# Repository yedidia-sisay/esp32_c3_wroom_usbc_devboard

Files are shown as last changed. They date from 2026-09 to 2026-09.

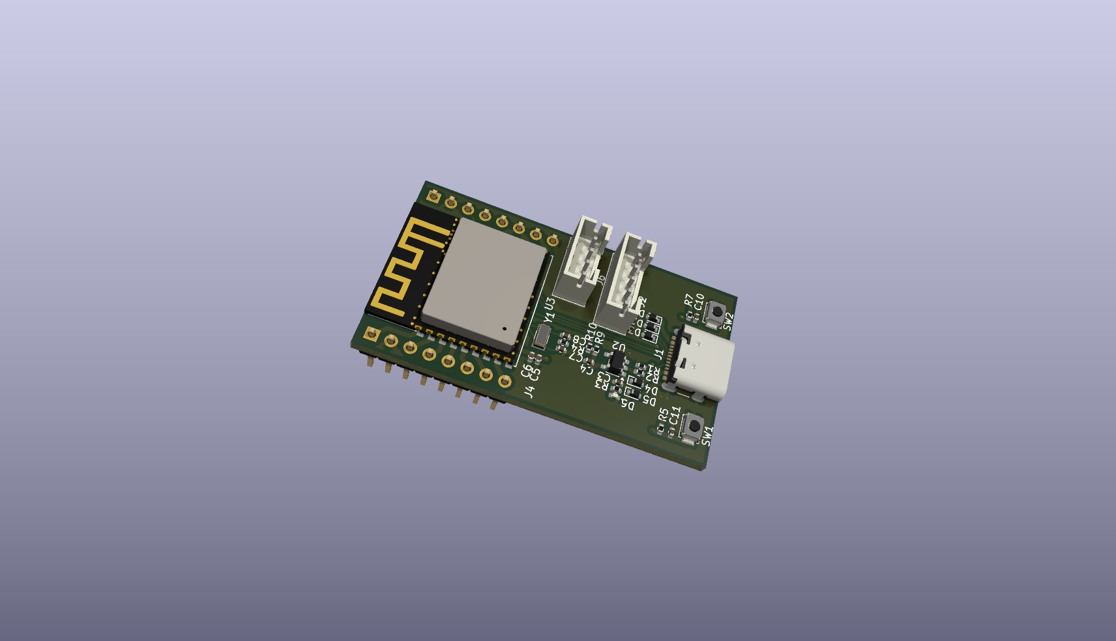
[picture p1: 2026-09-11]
esp32_devboard/esp32_devboard_1.png

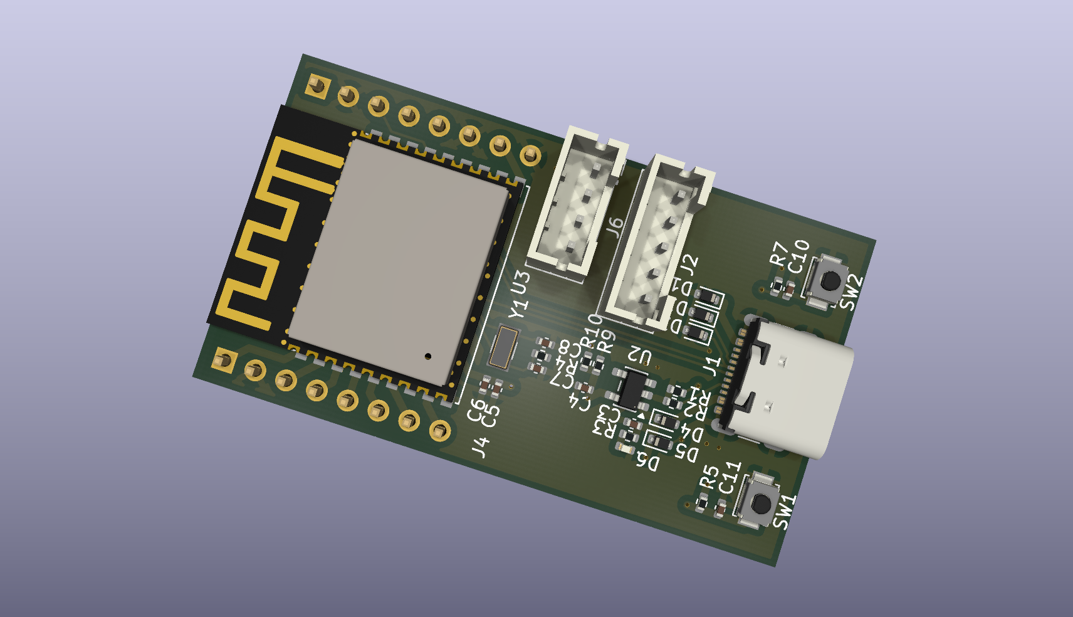
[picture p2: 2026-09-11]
esp32_devboard/esp32_devboard_2.png

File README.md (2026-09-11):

# ESP32-C3 Custom Development Board

A custom ESP32-C3 development board designed from the ground up in **KiCad**, covering schematic design, component selection, PCB layout, and routing.

The board is built around the **ESP32-C3-WROOM-02** and provides USB-C connectivity, regulated 3.3 V power, programming/debugging interfaces, GPIO expansion, and basic user controls.

## Overview

The goal of this project was to design a practical, compact ESP32-C3 development board rather than relying on an off-the-shelf development board.

The design integrates the ESP32-C3 module with the supporting power, USB, reset, boot, programming, and expansion circuitry required for a usable development platform.

## Features

* **ESP32-C3-WROOM-02** module
* **USB-C** connector
* USB 2.0 D+ / D− connectivity
* USB-C CC resistors
* USB ESD/TVS protection
* **5 V USB input**
* **3.3 V regulated supply**
* AP2112K-3.3 LDO
* Reset / CHIP_PU circuitry
* Boot-mode control
* User/status LED
* GPIO expansion headers
* Dedicated JTAG/UART access
* Exposed 3.3 V, 5 V, and GND connections
* Custom PCB layout and routing

## Hardware

### Main MCU

The board uses the **Espressif ESP32-C3-WROOM-02** module.

The module provides the main processing, USB connectivity, GPIO, UART, and debugging interfaces for the board.

The schematic exposes the ESP32-C3 GPIOs through headers so the board can be used for firmware development and hardware experimentation.

### USB-C

USB-C is used as the primary connection to the board.

The USB interface includes:

* VBUS power input
* USB D+
* USB D−
* CC1 / CC2 configuration resistors
* USB ESD/TVS protection
* Shield connection

The USB data lines connect directly to the ESP32-C3's native USB interface.

### Power

The board accepts **5 V from USB-C**.

A dedicated **AP2112K-3.3 LDO** generates the 3.3 V rail used by the ESP32-C3 and associated circuitry.
Decoupling capacitors are included around the power circuitry and ESP32-C3 supply.

### Reset and Boot

The board includes dedicated push buttons and supporting resistors for:

* ESP32 reset / CHIP_PU
* Boot-mode selection

This allows the module to be manually reset and placed into the required boot mode during firmware development.

### Programming and Debugging

The design exposes the ESP32-C3's programming/debugging signals through dedicated headers.

Interfaces available on the board include:

* UART
* JTAG
* GPIO
* 3.3 V
* 5 V
* GND

### GPIO Expansion

Two multi-pin headers provide access to the ESP32-C3 GPIOs.

This allows external sensors, peripherals, and prototype circuits to be connected without modifying the main PCB.

## PCB Design

The schematic and PCB were designed in **KiCad 10**.

The PCB design process included:

1. Component selection
2. Schematic capture
3. Electrical connectivity definition
4. Component footprint assignment
5. PCB placement
6. Power and signal routing
7. USB routing
8. Ground-plane implementation
9. Design-rule checking
10. Final PCB routing

The design was developed with the intention of producing a physically usable development board rather than being purely a schematic exercise.

# Project Status

**Hardware design completed.**

The schematic and PCB routing have been completed. The next stage is hardware fabrication and bring-up, followed by firmware testing and validation of the USB, power, GPIO, and programming interfaces.
## Author

**Yedidia Sisay**

Electrical Engineering | Embedded Systems | PCB Design

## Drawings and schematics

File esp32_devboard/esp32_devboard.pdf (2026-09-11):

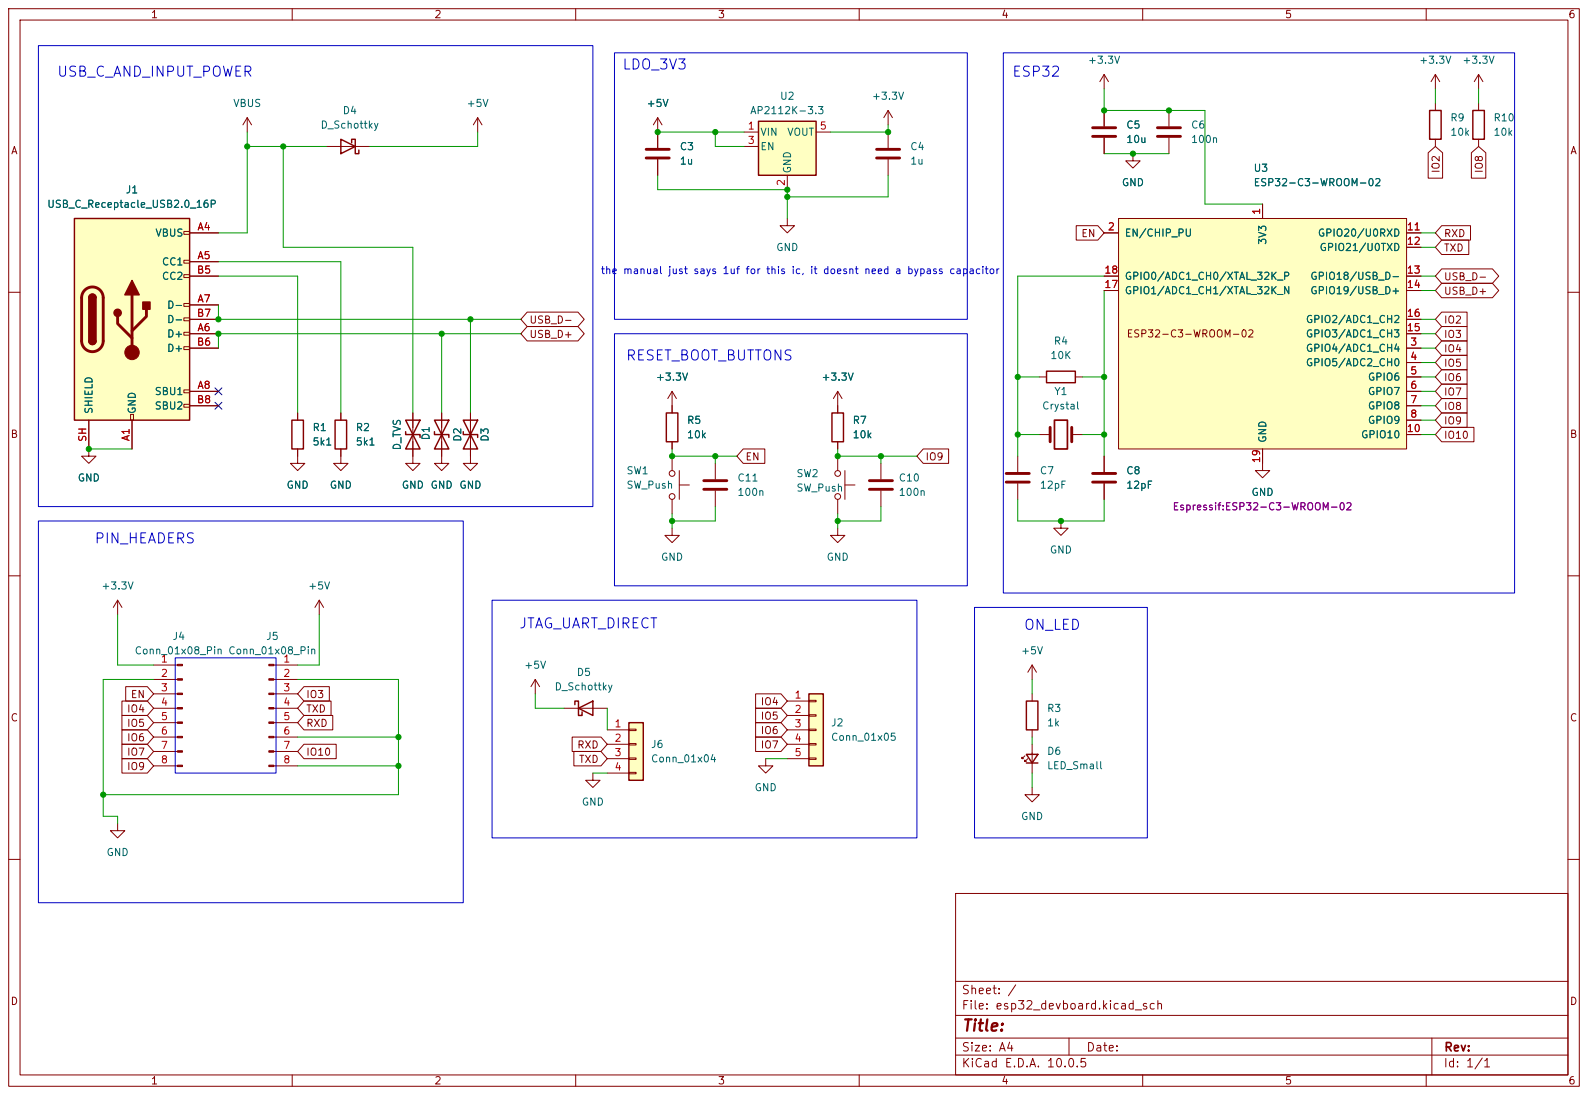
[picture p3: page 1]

the manual just says 1uf for this ic, it doesnt need a bypass capacitor

Size: A4 | Rev:
KiCad E.D.A. 10.0.5 | Id: 1/1

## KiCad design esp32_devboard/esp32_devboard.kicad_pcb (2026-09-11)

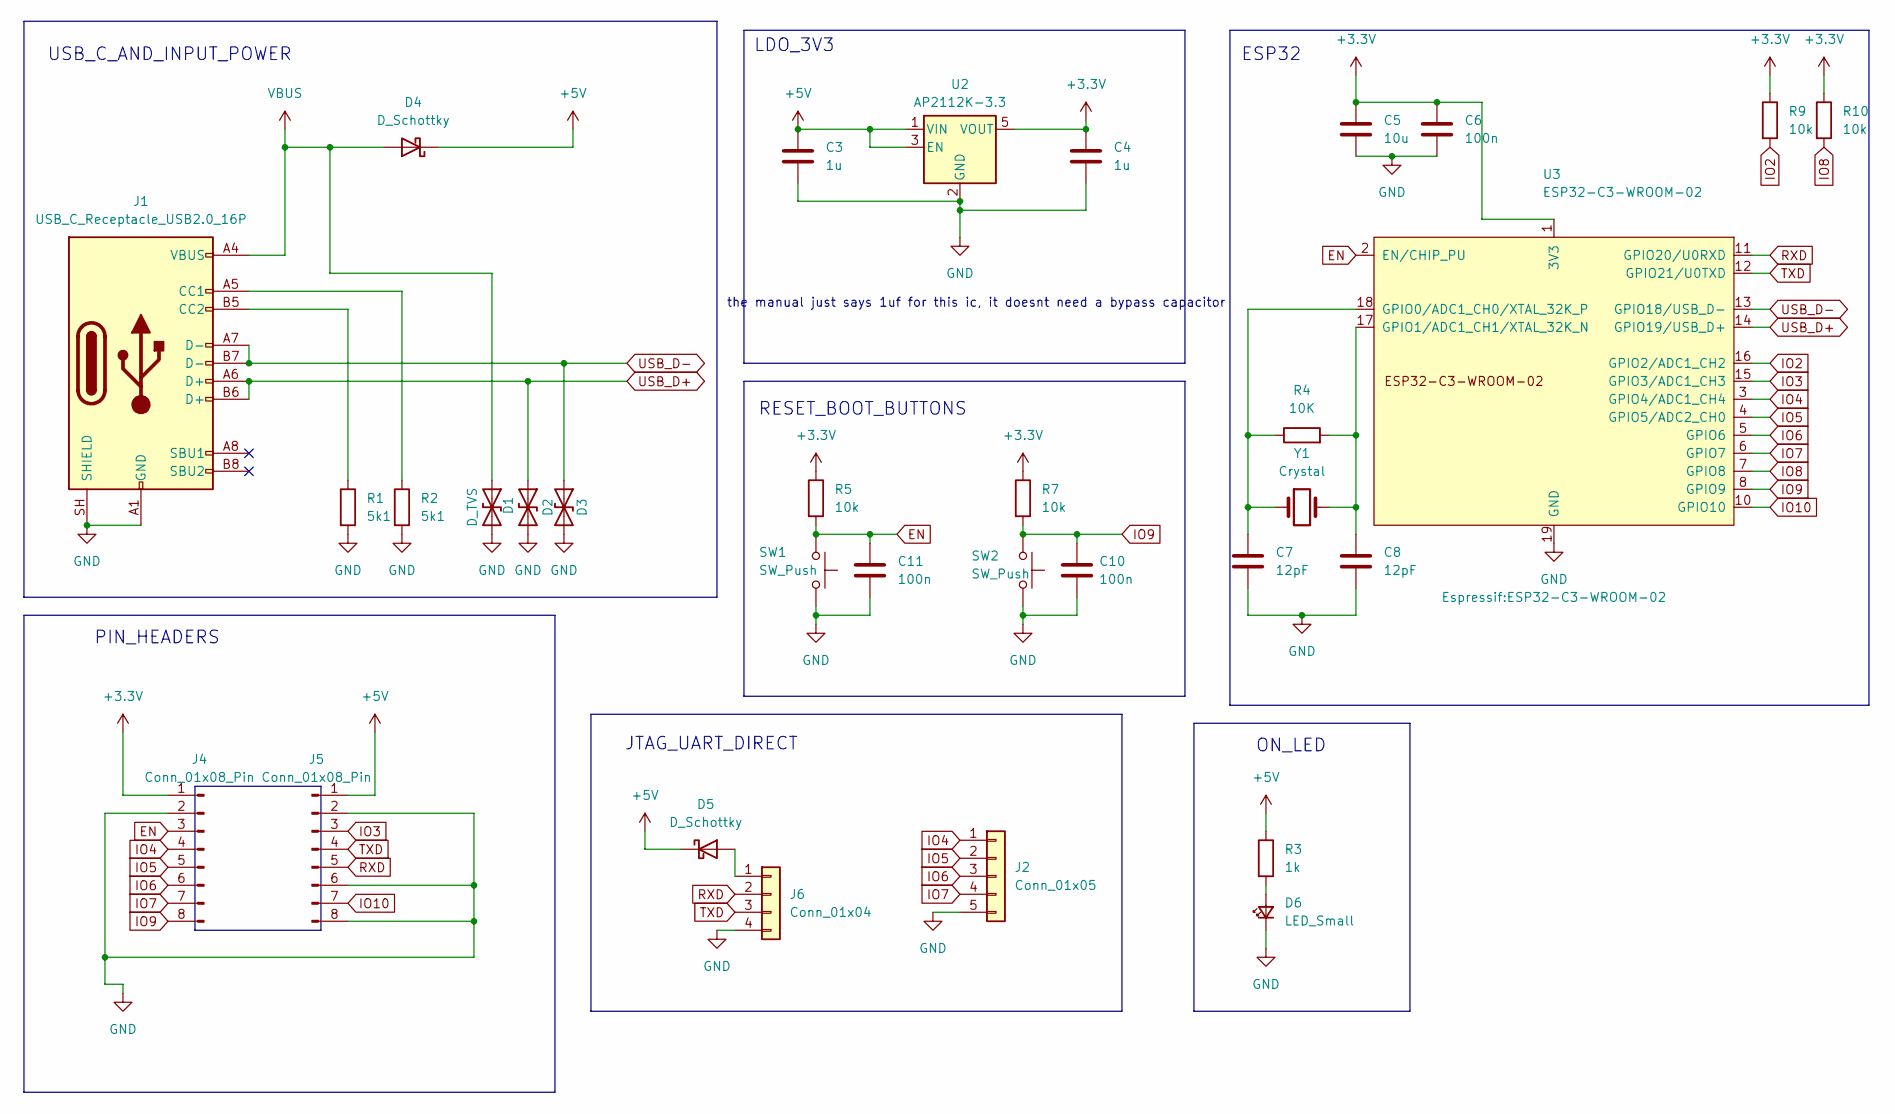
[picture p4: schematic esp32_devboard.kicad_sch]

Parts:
C3, C4: 1u; C_0402_1005Metric
C5: 10u; C_0402_1005Metric
C6, C10, C11: 100n; C_0402_1005Metric
C7, C8: 12pF; C_0402_1005Metric
D1, D2, D3: D_TVS; D_SOD-523
D4, D5: D_Schottky; D_SOD-523
D6: LED_Small; LED_0402_1005Metric
J1: USB_C_Receptacle_USB2.0_16P; USB_C_Receptacle_GCT_USB4105-xx-A_16P_TopMnt_Horizontal
J2: Conn_01x05; JST_PH_B5B-PH-K_1x05_P2.00mm_Vertical
J4, J5: Conn_01x08_Pin; PinHeader_1x08_P2.54mm_Vertical
J6: Conn_01x04; JST_PH_B4B-PH-K_1x04_P2.00mm_Vertical
R1, R2: 5k1; R_0402_1005Metric
R3: 1k; R_0402_1005Metric
R4: 10K; R_0402_1005Metric
R5, R7, R9, R10: 10k; R_0402_1005Metric
SW1, SW2: SW_Push; SW_SPST_B3U-1000P
U2: AP2112K-3.3; SOT-23-5
U3: ESP32-C3-WROOM-02
Y1: Crystal; Crystal_SMD_3215-2Pin_3.2x1.5mm

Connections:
+3.3V: C4.1, C5.1, C6.1, J4.1, R5.1, R7.1, R9.1, R10.1, U2.5 (VOUT), U3.1 (3V3)
+5V: C3.1, D4.1 (K), D5.1 (K), J5.1, R3.1, U2.1 (VIN), U2.3 (EN)
EN: C11.1, J4.3, R5.2, SW1.1, U3.2 (EN/CHIP_PU)
GND: C3.2, C4.2, C5.2, C6.2, C7.2, C8.2, C10.2, C11.2, D1.2 (A2), D2.2 (A2), D3.2 (A2), D6.1 (K), J1.A1 (GND), J1.A12 (GND), J1.B1 (GND), J1.B12 (GND), J1.SH (SHIELD), J2.5, J4.2, J5.2, J5.6, J5.8, J6.4, R1.2, R2.2, SW1.2, SW2.2, U2.2 (GND), U3.9 (GND), U3.19 (GND)
IO2: R9.2, U3.16 (GPIO2/ADC1_CH2)
IO3: J5.3, U3.15 (GPIO3/ADC1_CH3)
IO4: J2.1, J4.4, U3.3 (GPIO4/ADC1_CH4)
IO5: J2.2, J4.5, U3.4 (GPIO5/ADC2_CH0)
IO6: J2.3, J4.6, U3.5 (GPIO6)
IO7: J2.4, J4.7, U3.6 (GPIO7)
IO8: R10.2, U3.7 (GPIO8)
IO9: C10.1, J4.8, R7.2, SW2.1, U3.8 (GPIO9)
IO10: J5.7, U3.10 (GPIO10)
unnamed: D5.2 (A), J6.1
unnamed: D6.2 (A), R3.2
unnamed: J1.A5 (CC1), R2.1
unnamed: J1.B5 (CC2), R1.1
unnamed: C7.1, R4.1, U3.18 (GPIO0/ADC1_CH0/XTAL_32K_P), Y1.1
unnamed: C8.1, R4.2, U3.17 (GPIO1/ADC1_CH1/XTAL_32K_N), Y1.2
RXD: J5.5, J6.2, U3.11 (GPIO20/U0RXD)
TXD: J5.4, J6.3, U3.12 (GPIO21/U0TXD)
USB_D+: D2.1 (A1), J1.A6 (D+), J1.B6 (D+), U3.14 (GPIO19/USB_D+)
USB_D-: D3.1 (A1), J1.A7 (D-), J1.B7 (D-), U3.13 (GPIO18/USB_D-)
VBUS: D1.1 (A1), D4.2 (A), J1.A4 (VBUS), J1.A9 (VBUS), J1.B4 (VBUS), J1.B9 (VBUS)

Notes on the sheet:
the manual just says 1uf for this ic, it doesnt need a bypass capacitor
ESP32
USB_C_AND_INPUT_POWER
ON_LED
PIN_HEADERS
JTAG_UART_DIRECT
LDO_3V3
RESET_BOOT_BUTTONS

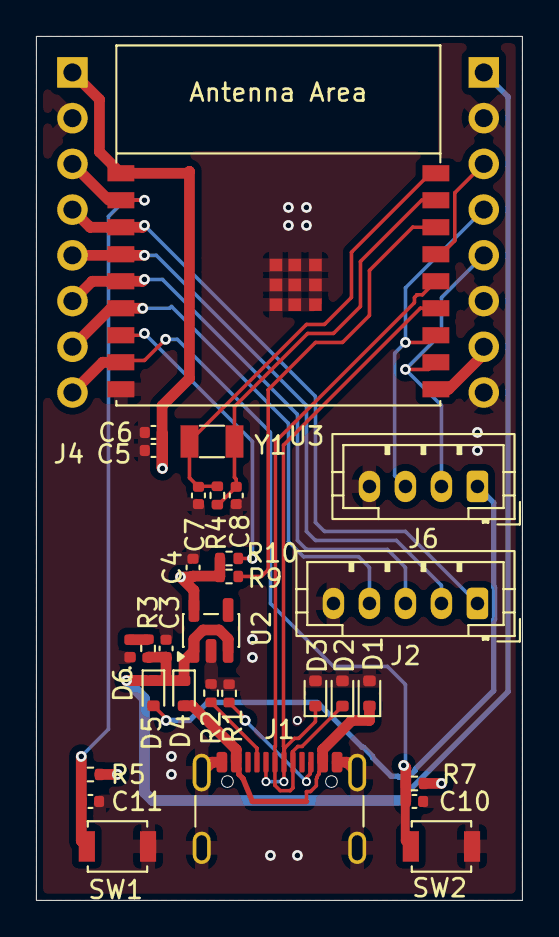
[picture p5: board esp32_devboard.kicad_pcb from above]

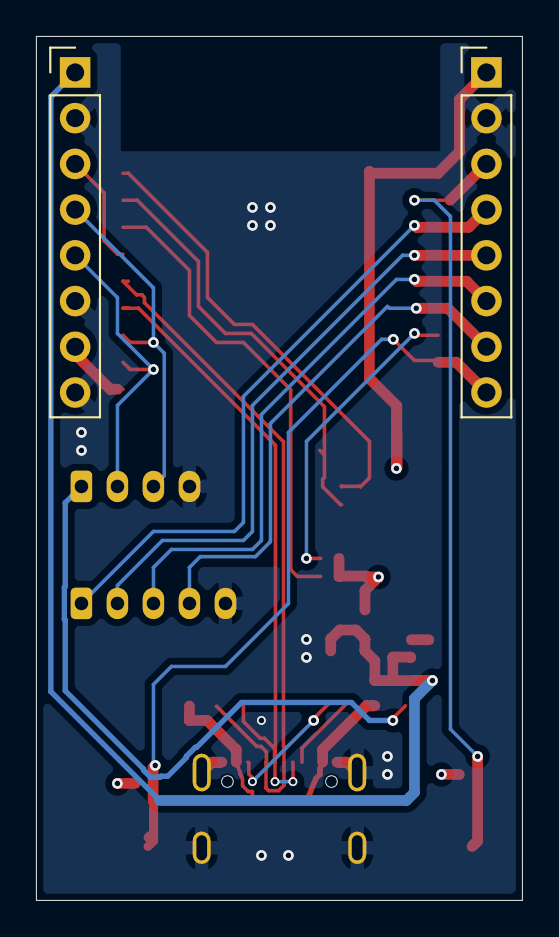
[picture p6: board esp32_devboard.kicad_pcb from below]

Board: 4 copper layers, 27.0 x 48.0 mm, 32 parts (2 on the bottom side), 24 nets.

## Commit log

2026-07-24 schematic, and placement
    [city.kicad_pcb, city.kicad_sch, esp32.kicad_sch]
2026-07-25 after routing
    [city.kicad_pcb, city.kicad_sch, esp32.kicad_sch]
2026-07-30 starting to add fixes and changing some dimensions
    [city.kicad_sch]
2026-09-11 so redid it an another folder and just copied it here
    [esp32_devboard.kicad_pcb, esp32_devboard.kicad_sch]
2026-09-11 Added Readme
    [city.kicad_pcb, city.kicad_sch, esp32.kicad_sch]
